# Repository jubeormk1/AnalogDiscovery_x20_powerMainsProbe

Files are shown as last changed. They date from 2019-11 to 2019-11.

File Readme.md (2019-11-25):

# ADVISE: This project is a work in progress

This is the first version of the instruments. Please review and make constructive comments about the design. Use under your own risk for evaluation purposes only. After my internal validation the an "Stable version will be release." After I get this right more board to improve the versatility of the great [AnalogDiscovery board by Agilent](https://analogdiscovery.com/) will be release.

# Introduction

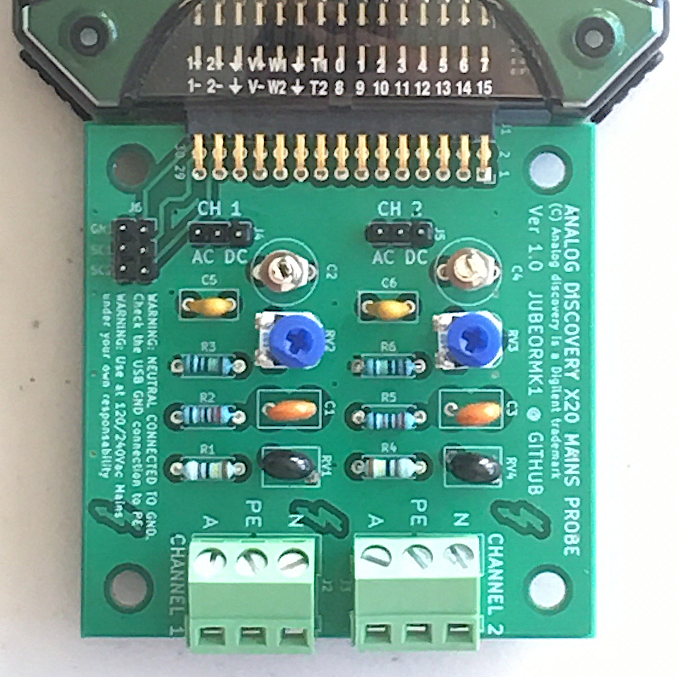
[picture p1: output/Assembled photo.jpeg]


This is a design initially created to look a the shape of mains outlets. I design it to check the total harmonic distortion of a generator outlet with a x20 reduction.

It has two inlets to measure two active line with the same neutral, i.e. the signal before and after a power line filter. It is intended to measure only voltage up to a frequency of at least 100kHz without a significant reduction of the signal (under 3db).

The connector is made to be connected to an Analog Discovery Digilent Instrument. It has been design to compensate the internal impedance of this particular instrument (1MOhm, 24pF). If you have one of these you can tune it so it works at it's best.

So far the version v0.1 has been release with some issues. This issues are related with the PCB layout, mainly related to the main connector pins and an unconnected pin. Apart from that the measured frequency response tested with flying wires is a success as you can see in the next frequency response analysis.

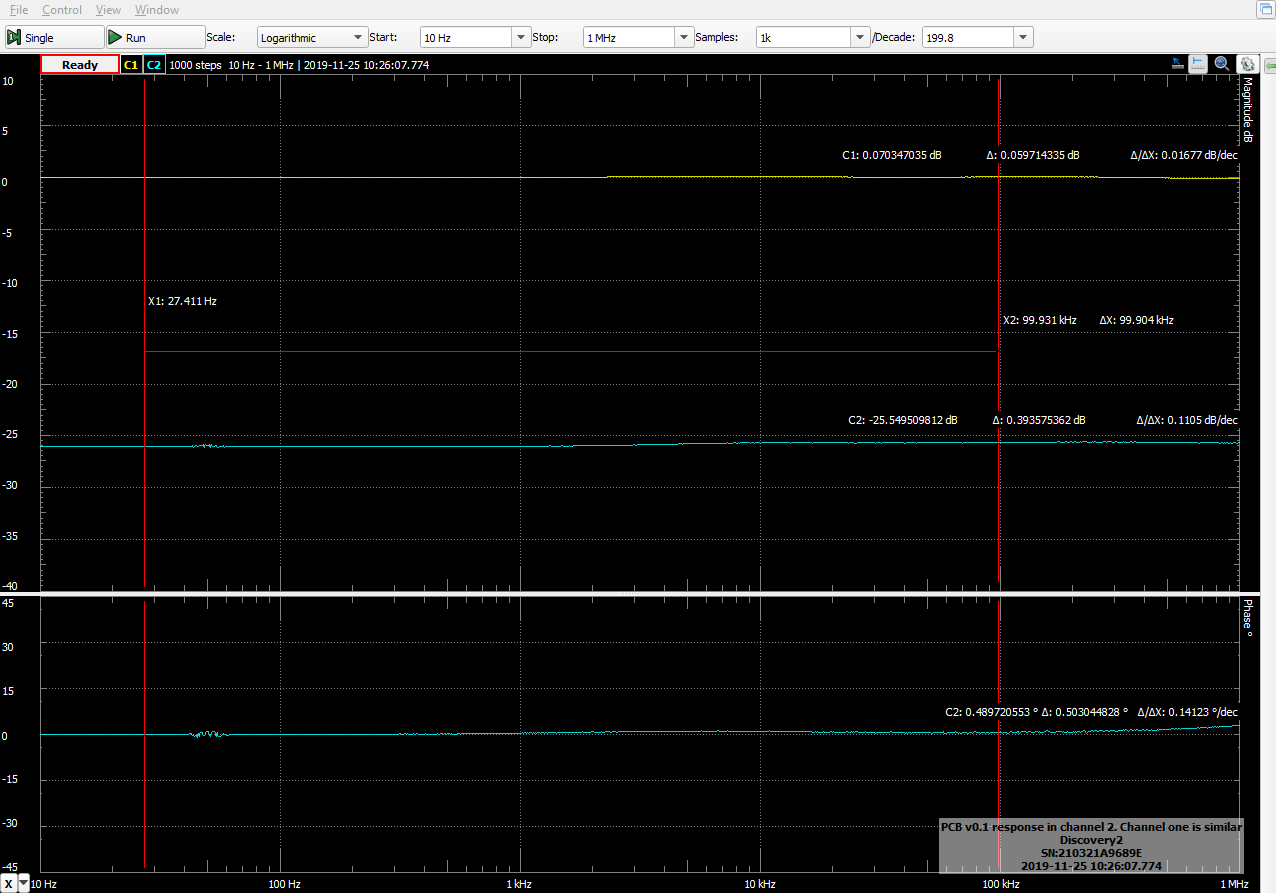
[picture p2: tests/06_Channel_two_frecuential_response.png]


The frequential response is almost flat with a small deviation only 0.39dB at 100kHz. The phase shift is kept close to zero for the whole analysis from 10Hz to 400kHz with an increasing positive slope from 400kHz ending under 5 degrees.

# Warnings

* This circuit is intended to be use to measure monophasic power mains up to 240Vrms. Such a voltage imply electric risk and only professionals with the right skills and safety protections should use it.

* The neutral of the power outlet under test will be connected to the GND of the instruments in use. Before any use make sure that there is no connection from the GND of the instrument with the protective heart (PE) of your installation.

* If the GND of your instrument is connected to PE you should isolate it using an appropiate method, which could be an isolation transformer.

* Prior to the first use it is necessary to adjust the gain of both channels using resistor trims. See the tune procedure section in this document to understand the procedure.

* If used without a plastic case, provide adequate means to prevent accidental contact with the AC voltage present by isolating the exposed metal points.

* If unsure about above conditions are met please don't use this design.

* Use under your responsibility

* Any damage caused by the use of this design is responsibility of the licensed professional using it

# Specifications

After tuned this circuit delivered:
* Two channels connected to scope 1 and 2
* An x20 attenuation in both channels
* AC/DC coupling mode via jumpers selection in each channels
* Impedance matching to obtain an  uniform amplitude and phase frequency response from DC to at least 100kHz
* Protection for over voltage (varistor) rated to the used device

# Tune procedure

This procedure consist in two tunning procedures and a measurement of the frequency response. The order is important in this procedure. Once tunned at the circuit best. The tunning procedure is made with very low voltages (5V). This is done to prevent any damage to the board or the instrument used. If unexpected volts appear please check the components values before continuing and correct any anomaly. A visual inspection of the board is also recommended to look for short circuits, missing components or bad soldering points.

## Required equipment:
* Personal Computer
* Digilent Analog Discovery (R) Instrument
* Software Digilent Waveforms(R)
* Small isolated flat screwdriver
* Male to male connection leads
* Recommended but not required: multimeter

## Tunning the gain of a channel

Repeat this procedure for channel one and channel two.

1. Connect the jumpers of the channel under test in DC position.
2. Connect a male to male lead from GEN1 to the  in the appropriated input connector with a the pin socket corresponding to the channel under test
3. Connect the extension board to an Analog Discovery Digilent Instrument
4. Using Waveforms>Wavegen generate a DC signal in generator 1 channel of 5 Volts
5. Using Waveforms>Scope or Waveforms>Voltmeter obtain the value at the channel that you are calibrating.
6. Turn the dial on the trim resistor until you obtain 5/20 V (0.25V)

## Tunning the frequency response of a channel

Repeat this procedure for channel one and channel two. Use the channel not being tested as auxiliary channel.

1. Connect the jumpers of each channels in DC position.
2. Connect a male to male lead from GEN1 to the  in the appropriated input connector with a the pin socket corresponding to the channel under test
3. Connect a male to male lead from the channel you are not testing to GEN1
4. Connect the extension board to an Analog Discovery Digilent Instrument
5. Using Waveforms>Wavegen generate an square signal in generator 1 channel of +-5 Volts at a frequency of 10Hz
6. Using Waveforms>Scope obtain a good scope of the rising edge of the signal generated by the waveform generator and the reading in the channel you are adjusting
7. At this point you should have a signal with an amplitude of 1/20 from the channel under test to the auxiliary channel.
7. Turn the dial on the trim capacitor until you get the smaller possible raising time without overshooting.

## Measurement of the frequency response.

Repeat this procedure for channel one and channel two. Use the channel not being tested as auxiliary channel. Do this after you calibrate the gain and the frequency response. You can do it beforehand to check how wrong the probe was and compare it to an adjusted channel.

1. Connect the jumpers of each channels in DC position.
2. Connect a male to male lead from GEN1 to the  in the appropriated input connector with a the pin socket corresponding to the channel under test
3. Connect a male to male lead from the channel you are not testing to GEN1
4. Connect the extension board to an Analog Discovery Digilent Instrument

5. Using Digilent Waveforms>Network Analyser configure an acquisition from 10Hz to 10MHz and 300 samples

6. Initiate a single acquisition

7. Note down the frequency where the signal drop 3dBs from the 10Hz response. This is the bandwidth of your channel

8. Note down the phase at it's minimum and maximum values

9. Repeat the frequency response tunning until you get the best bandwidth

# License

Analog Discovery (R) and Waveforms(R) are Digilent trademarks.

The license is described in the file 'LICENSE'.

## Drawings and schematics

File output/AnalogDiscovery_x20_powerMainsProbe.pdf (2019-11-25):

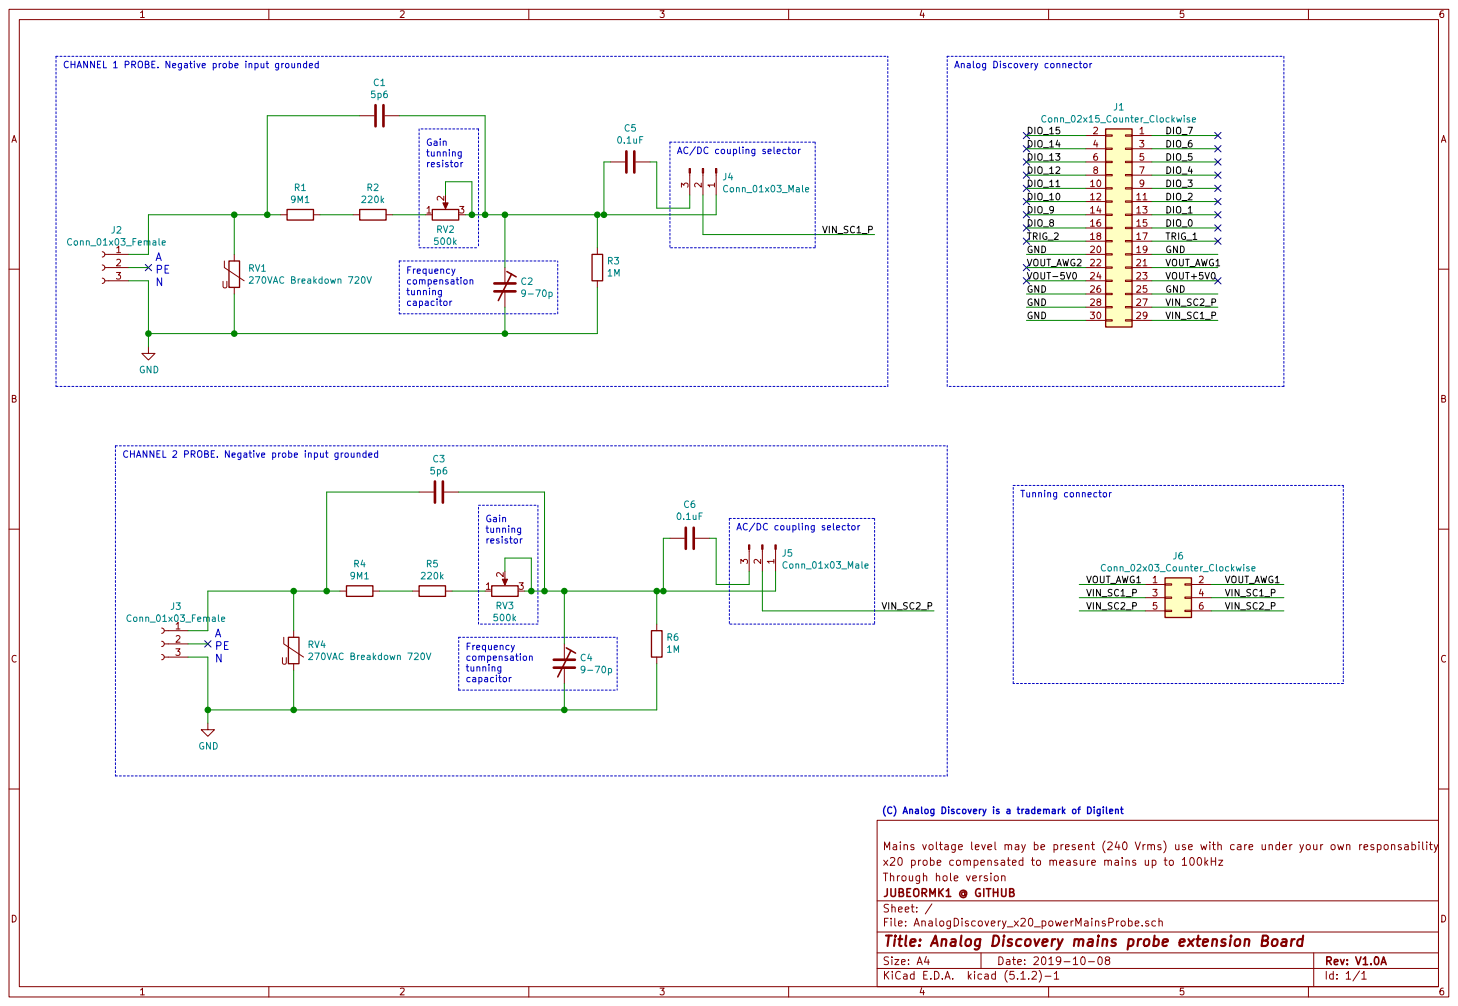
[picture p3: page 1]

CHANNEL 1 PROBE. Negative probe input grounded

AC/DC coupling selector

VOUT-5V0 VOUT_AWG2 GND
VOUT+5V0 VOUT_AWG1 GND GND GND

CHANNEL 2 PROBE. Negative probe input grounded

Mains voltage level may be present (240 Vrms) use with care under your own responsability
x20 probe compensated to measure mains up to 100kHz
Through hole version
File: AnalogDiscovery_x20_powerMainsProbe.sch Sheet: / JUBEORMK1 @ GITHUB

Id: 1/1 Title: Analog Discovery mains probe extension Board

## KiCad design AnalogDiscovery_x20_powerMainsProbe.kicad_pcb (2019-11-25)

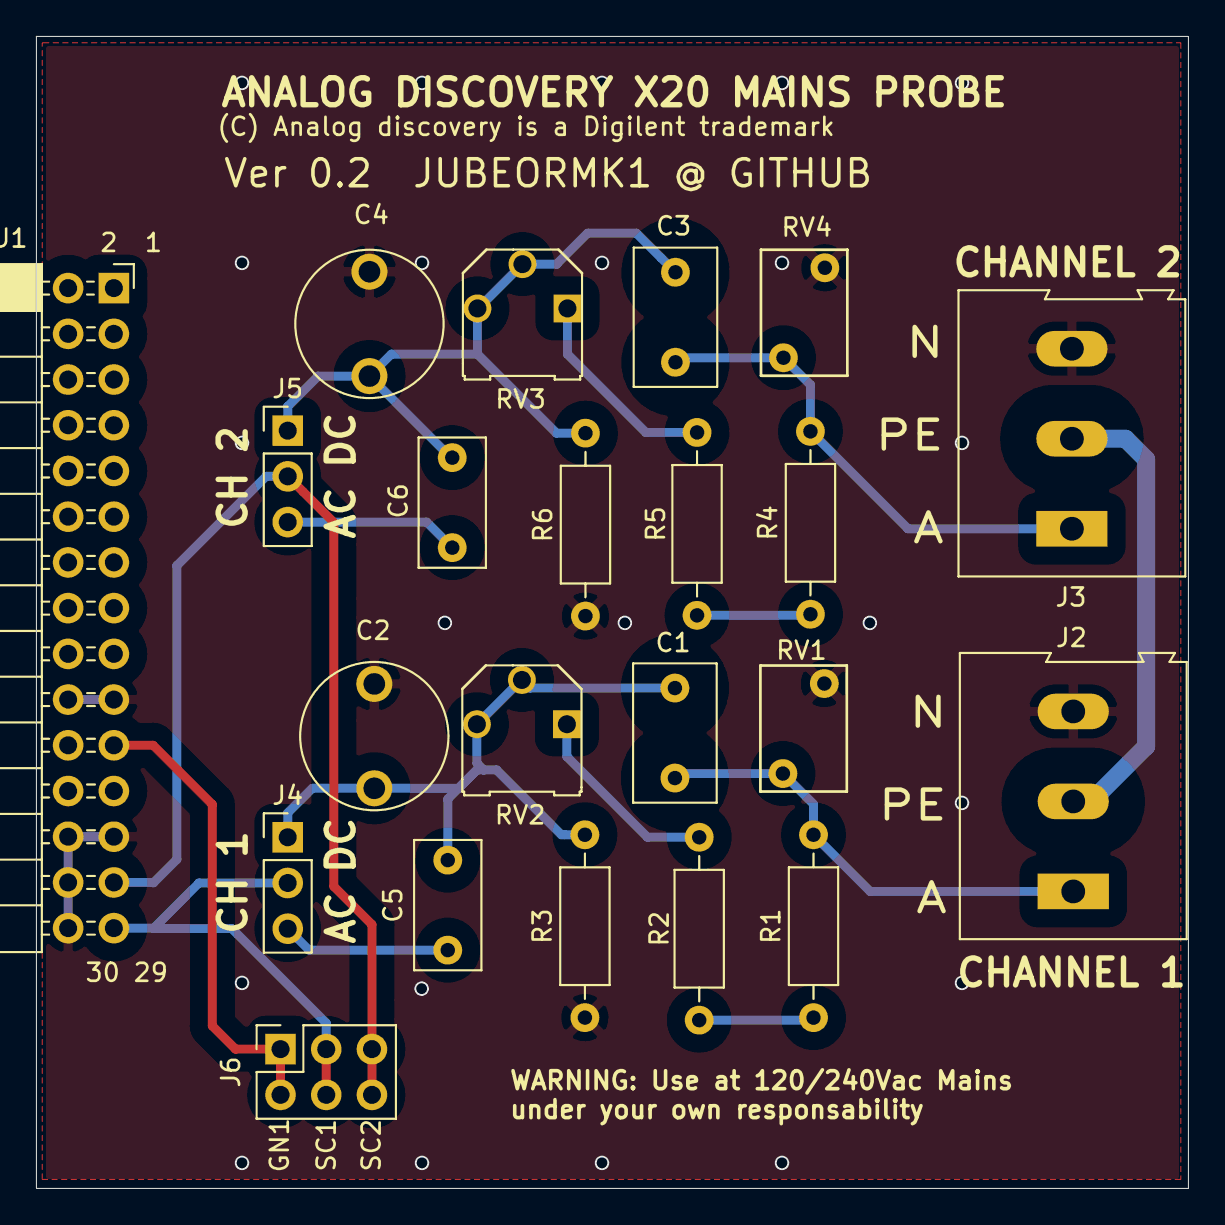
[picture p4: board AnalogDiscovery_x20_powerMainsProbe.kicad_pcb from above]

Board: 2 copper layers, 64.0 x 64.0 mm, 22 parts (0 on the bottom side), 14 nets.

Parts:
C1, C3: 5p6; C_Disc_D7.5mm_W4.4mm_P5.00mm
C2, C4: 9-70p; C_trimmer_Axial_6.7mm
C5, C6: 0.1uF; C_Rect_L7.0mm_W3.5mm_P5.00mm
J1: Conn_02x15_Counter_Clockwise; PinSocket_2x15_P2.54mm_Horizontal
J2, J3: Conn_01x03_Female; TerminalBlock_Altech_AK300-3_P5.00mm
J4, J5: Conn_01x03_Male; PinHeader_1x03_P2.54mm_Vertical
J6: Conn_02x03_Counter_Clockwise; PinSocket_2x03_P2.54mm_Vertical
R1, R4: 9M1; R_Axial_DIN0207_L6.3mm_D2.5mm_P10.16mm_Horizontal
R2, R5: 220k; R_Axial_DIN0207_L6.3mm_D2.5mm_P10.16mm_Horizontal
R3, R6: 1M; R_Axial_DIN0207_L6.3mm_D2.5mm_P10.16mm_Horizontal
RV1, RV4: 270VAC Breakdown 720V; RV_Disc_D7mm_W4.8mm_P5mm
RV2, RV3: 500k; Potentiometer_Bourns_3306P-1-504

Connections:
/VIN_SC1_P: J1.29, J4.2, J6.3, J6.4
/VIN_SC2_P: J1.27, J5.2, J6.5, J6.6
/VOUT_AWG1: J1.21, J6.1, J6.2
GND: C2.2, C4.2, J1.19, J1.20, J1.25, J1.26, J1.28, J1.30, J2.3, J3.3, R3.1, R6.1, RV1.2, RV4.2
unnamed: C1.1, C2.1, C5.1, J4.1, R3.2, RV2.2, RV2.3
unnamed: C1.2, J2.1, R1.2, RV1.1
unnamed: C3.1, C4.1, C6.1, J5.1, R6.2, RV3.2, RV3.3
unnamed: C3.2, J3.1, R4.2, RV4.1
unnamed: C5.2, J4.3
unnamed: C6.2, J5.3
unnamed: R1.1, R2.2
unnamed: R2.1, RV2.1
unnamed: R4.1, R5.2
unnamed: R5.1, RV3.1

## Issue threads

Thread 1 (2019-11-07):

Incorrect RV1 and RV2 Potentiometer footprint

jubeormk1, 2019-11-07:
The given footprint has an inadequate central hole distance. The PCB is usable but aesthetics and ease of assembly suffer.

jubeormk1, 2019-11-24:
Already assembled. Not perfect but OK. Anyway it is advisable to fix this

jubeormk1, 2019-11-25:
New footprint created to match the size of the part.

Closed 2019-11-25.

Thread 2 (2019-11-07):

RV1 insertion holes to narrow

jubeormk1, 2019-11-07:
The holes size for RV1 need to be extended according to the reference used.

jubeormk1, 2019-11-24:
It was fine for the reference used but a bigger hole would be an improvement.

jubeormk1, 2019-11-25:
changed to 0.8mm

Closed 2019-11-25.

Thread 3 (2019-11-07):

Connector J1 distance to edge needs review

jubeormk1, 2019-11-07:
Th distance to edge need to be reduced about 1 millimeter. Measure and correct

jubeormk1, 2019-11-24:
It is functional but the connector body should be exactly at the edge of the board.

jubeormk1, 2019-11-25:
All set

Closed 2019-11-25.

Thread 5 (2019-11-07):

Part used in connector J1 too wide

jubeormk1, 2019-11-07:
This part is about 0.2mm wider than acceptable. It does not freely get attached to the AD2 unit. Needs a replacement in the design.

In the current situation this can be fixed by sanding the side edges until fit. This is a slow workaround.

jubeormk1, 2019-11-24:
I had to sand it a bit to match the Analog Discovery port opening. The final width is close to 38.5mm measured with an average caliper.

jubeormk1, 2019-11-25:
According to the [datasheet](https://docs.rs-online.com/58c6/0900766b815ce533.pdf) of the part found at [rs-online] the socket width is 15x2.54 +  0.51 = 38.61 mm.

Taking into account my measurements the size is about 0.1mm too wide.

After researching different worldwide component providers, it is not easy to find a two row female header 2x15 pins. The only other place where I found it is at [aliexpress]. In this page the dimensions are not specified so it is not really an alternative. It is cheaper per unit so it may be tempting...

[aliexpress]: https://www.aliexpress.com/item/32950033778.html
[rs-online]: https://au.rs-online.com/web/p/pcb-sockets/7655783

jubeormk1, 2019-11-25:
According to the [datasheet](https://docs.rs-online.com/58c6/0900766b815ce533.pdf) of the part found at [rs-online] the socket width is 15x2.54 +  0.51 = 38.61 mm.

Taking into account my measurements the size is about 0.1mm too wide.

After researching different worldwide component providers, it is not easy to find a two row female header 2x15 pins. The only other place where I found it is at [aliexpress]. In this page the dimensions are not specified so it is not really an alternative. It is cheaper per unit so it may be tempting...

[aliexpress]: https://www.aliexpress.com/item/32950033778.html
[rs-online]: https://au.rs-online.com/web/p/pcb-sockets/7655783

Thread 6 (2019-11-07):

Add a commuter switches for easier calibration

jubeormk1, 2019-11-07:
A commuter switch can help to select the source input in the probe x20.
 - signal generator
 - Input connector

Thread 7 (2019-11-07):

Adjust the mounting hole size

jubeormk1, 2019-11-07:
Adjust so they fit tightly spacers.

jubeormk1, 2019-11-25:
This is not an issue or an improvement feature for this board.

I cannot find the source of the definition for tightly spacers but basically what I meant by using tightly spacers is to shift slightly every other pin in a pin row to help them staying in place even when not soldered.

Since this board is meant to be fully soldered there is no need for this feature in any connector of this project.

Closed 2019-11-25.

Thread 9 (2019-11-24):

Resistor pin separation to tight

jubeormk1, 2019-11-24:
The resistor pin separation is correct **BUT** a bit narrow, an additional separation of 2mm would make it easier to hand assemble the board. This should not be a problem since there is a lot of space.

Closed 2019-11-25.

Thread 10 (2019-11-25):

J1 Connector mirrored

jubeormk1, 2019-11-25:
This is the mayor bug in the board since it makes it non functional. The way to overcome this problem with the release v0.1 is to possition the connector in the bottom side of the board.

jubeormk1, 2019-11-25:
Fixed and integrated. Ready for next release

Closed 2019-11-25.

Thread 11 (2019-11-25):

negative connection of channel one is unconnected in J1

jubeormk1, 2019-11-25:
This makes the channel one unusable unless a flying wire is connected from this signal to ground.

jubeormk1, 2019-11-25:
Solved with fix #10

Closed 2019-11-25.

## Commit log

2019-10-08 First commit with the base design
    Including Readme, schematics, board, gerbers and drill files.
    [AnalogDiscovery_x20_powerMainsProbe-B_Cu.gbr, AnalogDiscovery_x20_powerMainsProbe-B_Mask.gbr, AnalogDiscovery_x20_powerMainsProbe-B_SilkS.gbr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]
2019-11-24 Assembled circuit for version 1.0
    This is the first pcb version. I am pretty sure that it is going to work fine since there is not much change from the previous prototypes. **There are two jumpers missing in the photo, they should go in the jumpers j4 and j5**
2019-11-24 Updated Readme.md
    - Advising that this project is still in a prerelease
    - Adding an image to the first PCB assembled
2019-11-25 Updated Readme.md
    Added some information related to the test with the board v0.1 release.
    Fixed several typos. Shame on me!
2019-11-25 Solved issue #10
    [AnalogDiscovery_x20_powerMainsProbe.kicad_pcb, AnalogDiscovery_x20_powerMainsProbe.sch]
2019-11-25 Issue #3 fixed.
    J1 aligned with board edge
    [AnalogDiscovery_x20_powerMainsProbe.kicad_pcb]
2019-11-25 Issue #9 fixed. The resistor pin separation has been change from 6 to 10mm
    [AnalogDiscovery_x20_powerMainsProbe.kicad_pcb, AnalogDiscovery_x20_powerMainsProbe.sch]
2019-11-25 issue #2 Hole size updated to 0.8mm
    [AnalogDiscovery_x20_powerMainsProbe.kicad_pcb]
2019-11-25 Footprint fixed for potentiometers
    [AnalogDiscovery_x20_powerMainsProbe.kicad_pcb, AnalogDiscovery_x20_powerMainsProbe.sch]
